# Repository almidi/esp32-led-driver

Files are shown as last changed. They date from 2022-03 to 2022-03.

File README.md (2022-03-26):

# ESP32 Led Driver
ESP32 based 4-channel led driver for home automation.
Schematics and PCB design where originally developed on EasyEDA.
This example uses ESP-Home for integration with HomeAssistant.

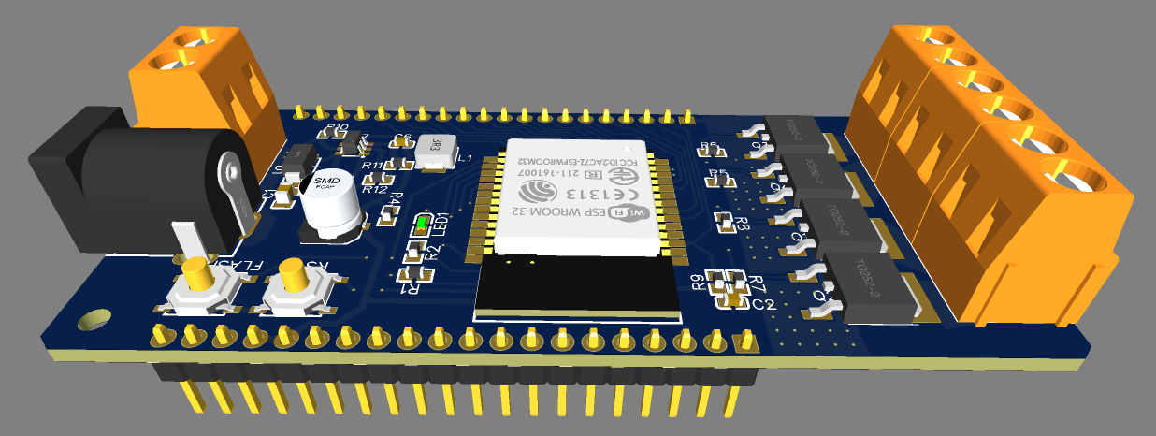
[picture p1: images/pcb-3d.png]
ESP32 Led Driver PCB


## BOM

|ID	 |Name	 |Designator	 |Footprint	 |Quantity	|Manufacturer Part	 |Manufacturer |
|---|---|---|---|---|---|---|
| 1 	|10uF 	 |C1 	 |C0805 	 |1 	 |CL21A106KAYNNNE 	 |SAMSUNG |
| 2 	|22uF 	 |C2 	 |C0603 	 |1 	 |CL10A226MQ8NRNC 	 |SAMSUNG |
| 3 	|22nF 	 |C3 	 |C0603 	 |1 	 |CL10B223KB8NNNC 	 |SAMSUNG |
| 4 	|47uF 	 |C4 	 |CAP-SMD_BD5.0-L5.3-W5.3-RD 	 |1 	 |VES470M1CTR-0505 	 |Lelon |
| 5 	|100pF 	 |C6 	 |C0603 	 |1 	 |CL10C101JB8NNNC 	 |SAMSUNG |
| 6 	|B230A-13-F 	 |D1 	 |SMA_L4.4-W2.6-LS5.0-RD 	 |1 	 |B230A-13-F 	 |DIODES |
| 7 	|DC-005-5A-2.0 	 |DC1 	 |DC-IN-TH_DC-005-5A-2.0 	 |1 	 |DC-005-5A-2.0 	 |XKB Enterprise |
| 8 	|TS-1187A-B-A-B 	 |FLASH,RST 	 |SW-SMD_4P-L5.1-W5.1-P3.70-LS6.4 	 |2 	 |TS-1187A-B-A-B 	 |XKB Enterprise |
| 9 	|Top Header 	 |J1 	 |HDR-TH_20P-P2.54-V 	 |1 	 |2.54mm 1*20PHeader 	|BOOMELE |
| 10 	|Bottom Header 	 |J2 	 |HDR-TH_20P-P2.54-V 	 |1 	 |2.54mm 1*20PHeader 	|BOOMELE |
| 11 	|3.3uH 	 |L1 	 |IND-SMD_L4.2-W4.4_MWSA0402S-XX 	 |1 	 |MWSA0402S-3R3MT 	 |Sunlord |
| 12 	|0603White light_C2290 	 |LED1 	 |LED0603-R-RD 	 |1 	 |0603White light 	 |KENTO |
| 13 	|KIA30N06BD 	 |Q1,Q2,Q3,Q4 	 |TO-252-2_L6.6-W6.1-P4.57-LS9.9-TL-CW 	|4 	 |KIA30N06BD 	 |KIA |
| 14 	|1K 	 |R1,R4,R5,R6,R7,R8,R9 	 |R0603 	 |7 	 |0603WAF1001T5E 	 |UniOhm |
| 15 	|100 	 |R2 	 |R0603 	 |1 	 |0603WAF1000T5E 	 |UniOhm |
| 16 	|100K 	 |R10 	 |R0603 	 |1 	 |0603WAF1003T5E 	 |UniOhm |
| 17 	|49.9K 	 |R11 	 |R0603 	 |1 	 |0603WAF4992T5E 	 |UniOhm |
| 18 	|16.2K 	 |R12 	 |R0603 	 |1 	 |0603WAF1622T5E 	 |UniOhm |
| 19 	|ESP32-S 	 |U1 	 |WIRELM-SMD_ESP32-S 	 |1 	 |ESP32-S 	 |Ai-Thinker |
| 20 	|DB128V-5.0-2P-OG 	 |U3,U4,U5,U6 	 |CONN-TH_DB128V-5.0-2P-XX 	 |4 	 |DB128V-5.0-2P-OG 	 |DIBO |
| 21 	|AP5100WG-7 	 |U7 	 |SOT-23-6_L2.9-W1.6-P0.95-LS2.8-BR 	|1	 |AP5100WG-7	 |DIODES |

Additionally a series of enclosures are designed for different use-cases.

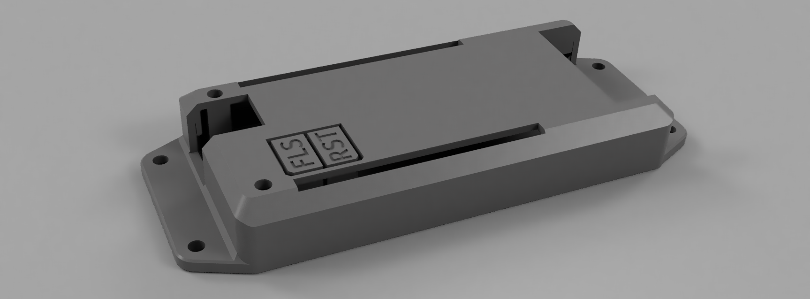
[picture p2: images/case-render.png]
ESP32 Led Driver Case


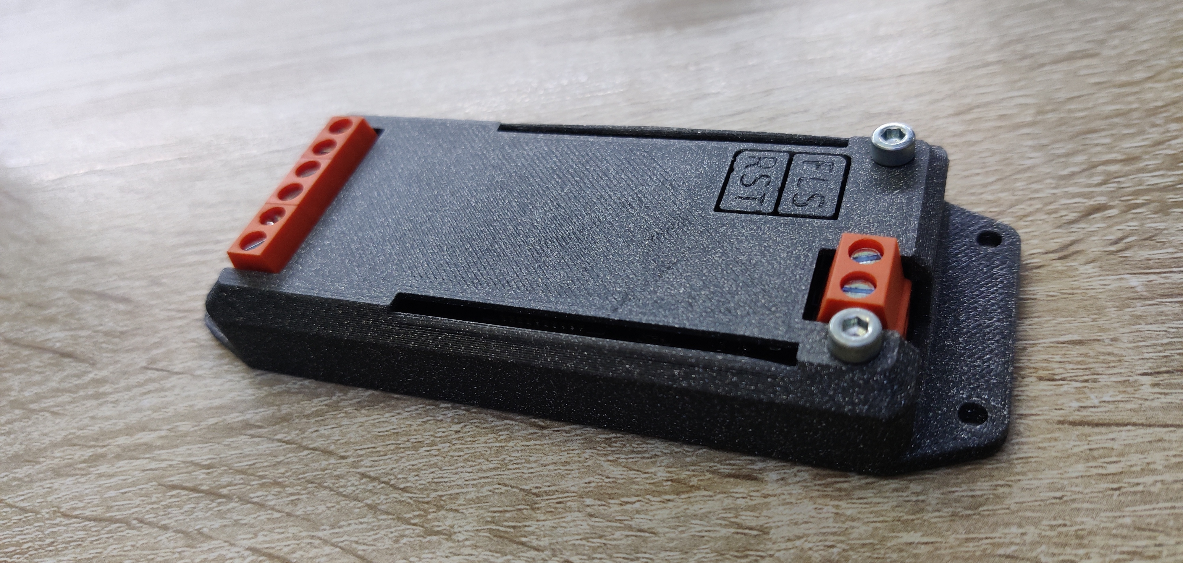
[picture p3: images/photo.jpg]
ESP32 Led Driver


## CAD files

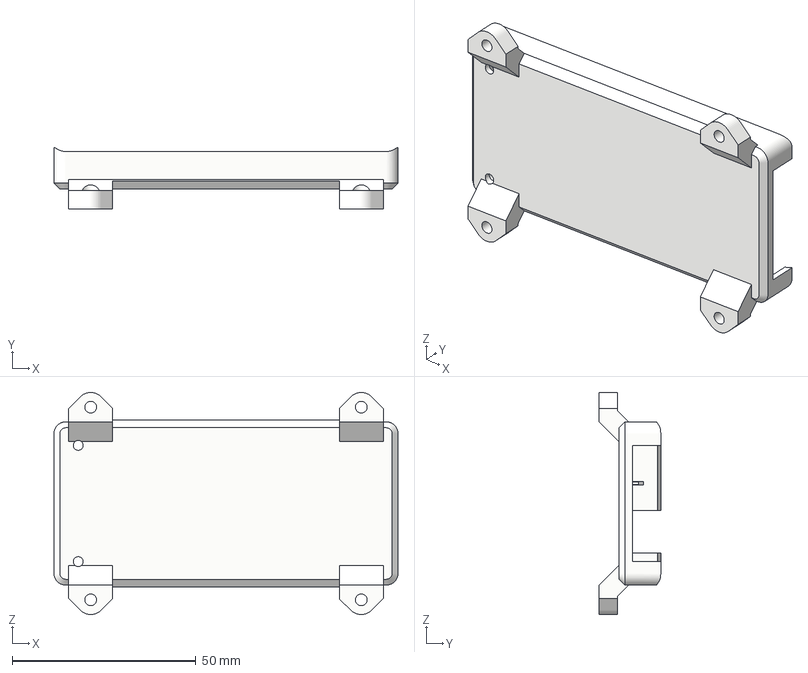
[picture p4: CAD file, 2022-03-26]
stl/body_feet.3mf
93.7 x 16.8 x 60.5 mm

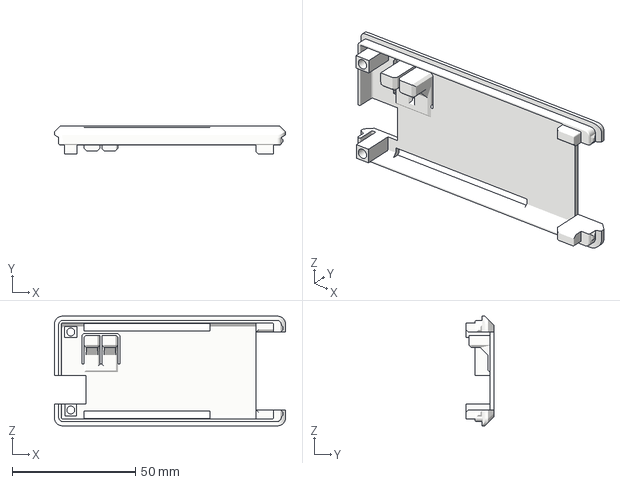
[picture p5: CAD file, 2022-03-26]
stl/cap_slots.3mf
93.7 x 11.3 x 44.5 mm

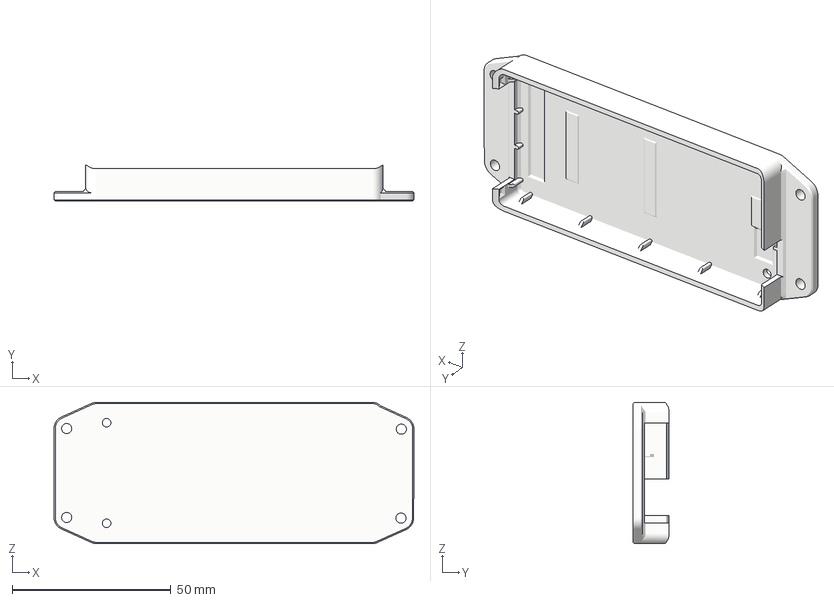
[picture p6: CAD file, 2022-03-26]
stl/body_flaps.3mf
113.4 x 11.4 x 44.5 mm

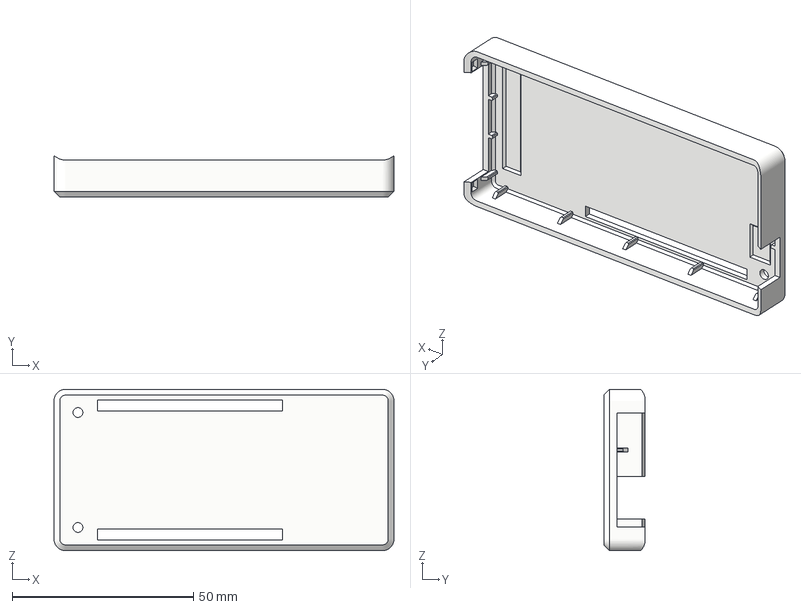
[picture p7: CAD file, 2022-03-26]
stl/body_slots.3mf
93.7 x 11.4 x 44.5 mm

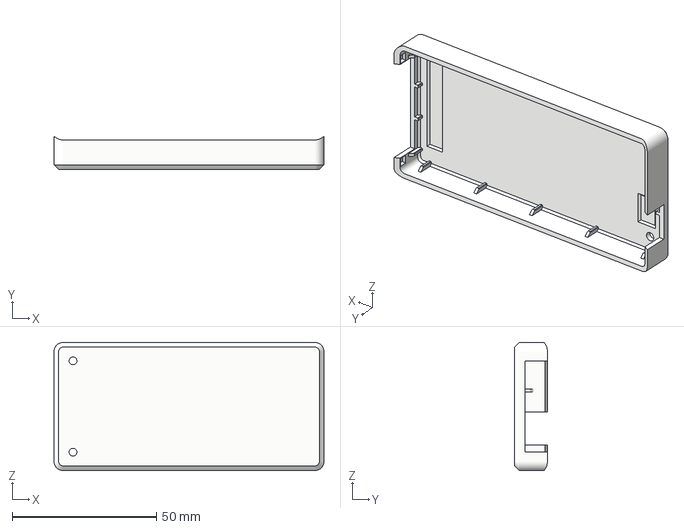
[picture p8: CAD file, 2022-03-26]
stl/body.3mf
93.7 x 11.4 x 44.5 mm

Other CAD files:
stl/cap.3mf
stl/body_feet_slots.3mf
stl/body_flaps_slots.3mf

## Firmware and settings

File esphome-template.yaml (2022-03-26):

esphome:
  name: <<NODE NAME>>
  platform: ESP32
  board: 'esp-wrover-kit'

wifi:
  ssid: '<<SSID>>'
  password: '<<PASSWORD>>'
  manual_ip:
   # Set this to the IP of the ESP
   static_ip: <<STATIC_IP>>
   # Set this to the IP address of the router. Often ends with .1
   gateway: 192.168.1.1
   # The subnet of the network. 255.255.255.0 works for most home networks.
   subnet: 255.255.255.0


# # Enable logging
logger:
  level: DEBUG

# Enable Home Assistant API
api:
  password: '<<PASSWORD>>'

ota:
  password: '<<PASSWORD>>'

#Outputs

output:
  - platform: ledc
    pin: 33
    frequency: 9765Hz
    id: red_led

  - platform: ledc
    pin: 32
    frequency: 9765Hz
    id: green_led

  - platform: ledc
    pin: 14
    frequency: 9765Hz
    id: blue_led

  - platform: ledc
    pin: 27
    frequency: 9765Hz
    id: white_led

  - platform: ledc
    pin: 2
    frequency: 9765Hz
    id: status_led

# RGB + W
light:
  - platform: rgb
    name: "RGB"
    red: red_led
    green: green_led
    blue: blue_led
    effects:
    - flicker:
        alpha: 80%
        intensity: 4%      
    - random:
    - random:
        name: Medium Random
        transition_length: 3s
        update_interval: 3s 
    - random:
        name: Fast Random
        transition_length: 20ms
        update_interval: 100ms      
    - strobe:
        colors:
          - state: True
            brightness: 100%
            duration: 10ms
          - state: False
            duration: 80ms

  - platform: monochromatic
    name: "W"
    output: white_led
    gamma_correct: 0
    effects:
    - flicker:
        alpha: 80%
        intensity: 2%
    - flicker:
        name: Extreme Flicker
        alpha: 100%
        intensity: 100%      
    - strobe:
        colors:
          - state: True
            brightness: 100%
            duration: 10ms
          - state: False
            duration: 80ms   

  - platform: monochromatic
    name: status
    id: status
    output: status_led
    gamma_correct: 0
    effects:
    - strobe:
        colors:
          - state: True
            brightness: 30%
            duration: 120ms
          - state: False
            duration: 120ms  

interval:
  - interval: 500ms
    then:
    - if:
        condition:
          wifi.connected:
        then:
          - light.turn_off: 
              id: status
              transition_length: 120ms
        else:
          - light.turn_on: 
              id: status 
              effect: strobe
